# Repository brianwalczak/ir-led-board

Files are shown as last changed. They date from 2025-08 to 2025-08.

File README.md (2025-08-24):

# `ir-led-board`
A custom circuit connecting 16 high-current IR LEDs, designed for integration with Raspberry Pi and imaging projects.

Check out my [JOURNAL.md](JOURNAL.md) for updates and progress!

> [!NOTE]  
> All custom footprints in this project, as well as 3D print files, were created by me and are freely available under the MIT license. You are completely welcome to use, modify, and distribute them without any restrictions.

#### PCB Design
A custom-designed printed circuit board, designed in KiCad 9.0, allowing you to control 16 IR LEDs in groups of four. This PCB was designed as an easy way to connect the components and use them via GPIO pins on the Raspberry Pi.

PCB Design

👉 [Read More](KiCad_PCB/README.md)

#### 3D Model (case)
A 3D printable case, designed in Fusion 360, made to securely hold the board and its components, as well as providing protection to prevent damage to the board.

3D Design
<br>
STL Model

👉 [Read More](3D_Print/README.md)

#### Bill of Materials (BOM)

| Qty | Part Number | Total Price |
|-----|---|---|
| 5 | JLCPCB: PCB Print | $5.30 |
| 1 | Raspberry Pi Camera 3 NoIR | $25.00 |
| 1 | Raspberry Pi 5 Camera Cable | $1.10 |
| 16  | SFH 4556-AW (850nm IR LEDs) | $9.47 |
| 16  | CFM12JT43R0 (43 Ohms resistor) | $0.58 |
| 4 | IRLB8743PBF (MOSFETs) | $4.76 |
| 4 | DC0011 (thermal pads) | $2.20 |
| 4 | CF14JT100R (100 Ohms resistor) | $0.24 |
| 4 | CF14JT100K (100K Ohms resistor) | $0.24 |
| 1 | PPPC061LGBN-RC (90-degree connector) | $0.57 |
| | **Total** | **$49.46**  |

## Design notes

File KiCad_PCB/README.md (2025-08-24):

# `ir-led-board` - KiCad PCB
> [!NOTE]  
> All custom footprints in this project were created by me and are freely available under the MIT license. You are completely welcome to use, modify, and distribute them without any restrictions.

Welcome! This folder includes a custom-designed printed circuit board for the `ir-led-board`, allowing you to control 16 IR LEDs in groups of four. This PCB was designed as an easy way to connect the components and use them via GPIO pins on the Raspberry Pi.

This PCB was designed in KiCad (you can import it with `File > Open Project` and exported as a ready-to-print Gerber file. This PCB can be printed for about **~$2.00** (quantity of 5) on [JLCPCB](https://jlcpcb.com/) (not sponsored).

**All routing has been automatically done by [Freerouting](https://github.com/freerouting/freerouting): an open-source auto-router for KiCad, built with Java.**

#### Schematic
Schematic

#### PCB Design
PCB Design

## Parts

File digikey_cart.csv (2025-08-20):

Index | Quantity | Part Number | Manufacturer Part Number | Description | Customer Reference | Available | Backorder | Unit Price | Extended Price USD
1 | 16 | S43HCT-ND | CFM12JT43R0 | RES 43 OHM 5% 1/2W AXIAL | 16x needed, for each IR LED | 16 | 0 | 0.03100 | 0.50
2 | 16 | 475-SFH4556-AW-ND | SFH 4556-AW | RADIAL T1 3/4 | 16x needed, 4 per group | 16 | 0 | 0.59200 | 9.47
3 | 1 | 2648-SC0873-ND | SC0873 | RASPBERRY PI CAMERA 3 NOIR | Camera used for Near-IR imaging | 1 | 0 | 25.00000 | 25.00
4 | 4 | IRLB8743PBF-ND | IRLB8743PBF | MOSFET N-CH 30V 78A TO220AB | Used to control 4 groups of LEDs | 4 | 0 | 1.19000 | 4.76
5 | 10 | CF14JT100RCT-ND | CF14JT100R | RES 100 OHM 5% 1/4W AXIAL | [10x is cheaper] Used at the gate to GPIO pin | 10 | 0 | 0.02100 | 0.21
6 | 10 | CF14JT100KCT-ND | CF14JT100K | RES 100K OHM 5% 1/4W AXIAL | [10x is cheaper] Pull-down resistor (Gate toGND) | 10 | 0 | 0.02100 | 0.21
7 | 1 | S5481-ND | PPPC061LGBN-RC | CONN HDR 6POS 0.1 GOLD PCB R/A | 90 degree connector for jumper wires | 1 | 0 | 0.57000 | 0.57
8 | 4 | 1168-1804-ND | DC0011/08-TI900-0.12-2A | THERM PAD 19.05MMX12.7MM W/ADH | Thermal pad for MOSFETs | 4 | 0 | 0.55000 | 2.20
9 | 1 | 2648-SC1129-ND | SC1129 | RPI 5 CAMERA CABLE 300MM | The 200mm is out of stock... | 1 | 0 | 2.00000 | 2.00

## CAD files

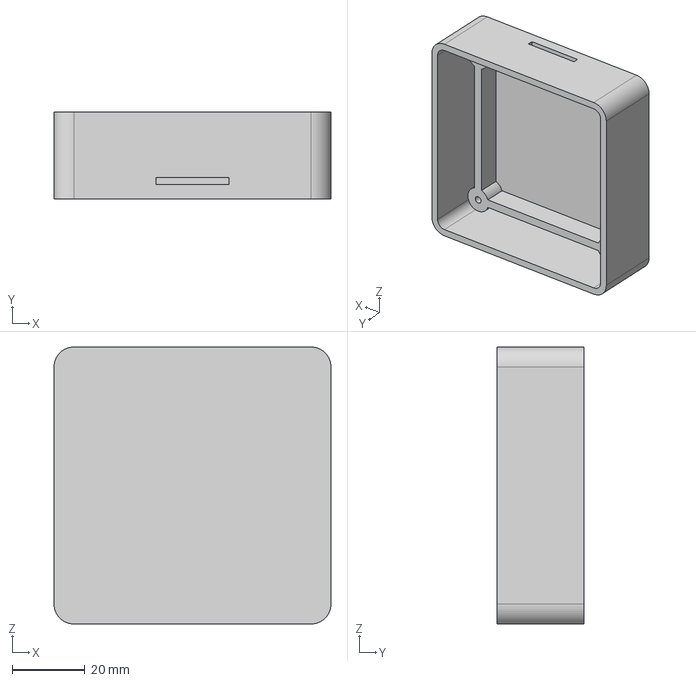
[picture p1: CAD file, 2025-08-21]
3D_Print/ir-led-board v5.step
76.4 x 24.0 x 76.4 mm

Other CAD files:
3D_Print/ir-led-board v5.stl

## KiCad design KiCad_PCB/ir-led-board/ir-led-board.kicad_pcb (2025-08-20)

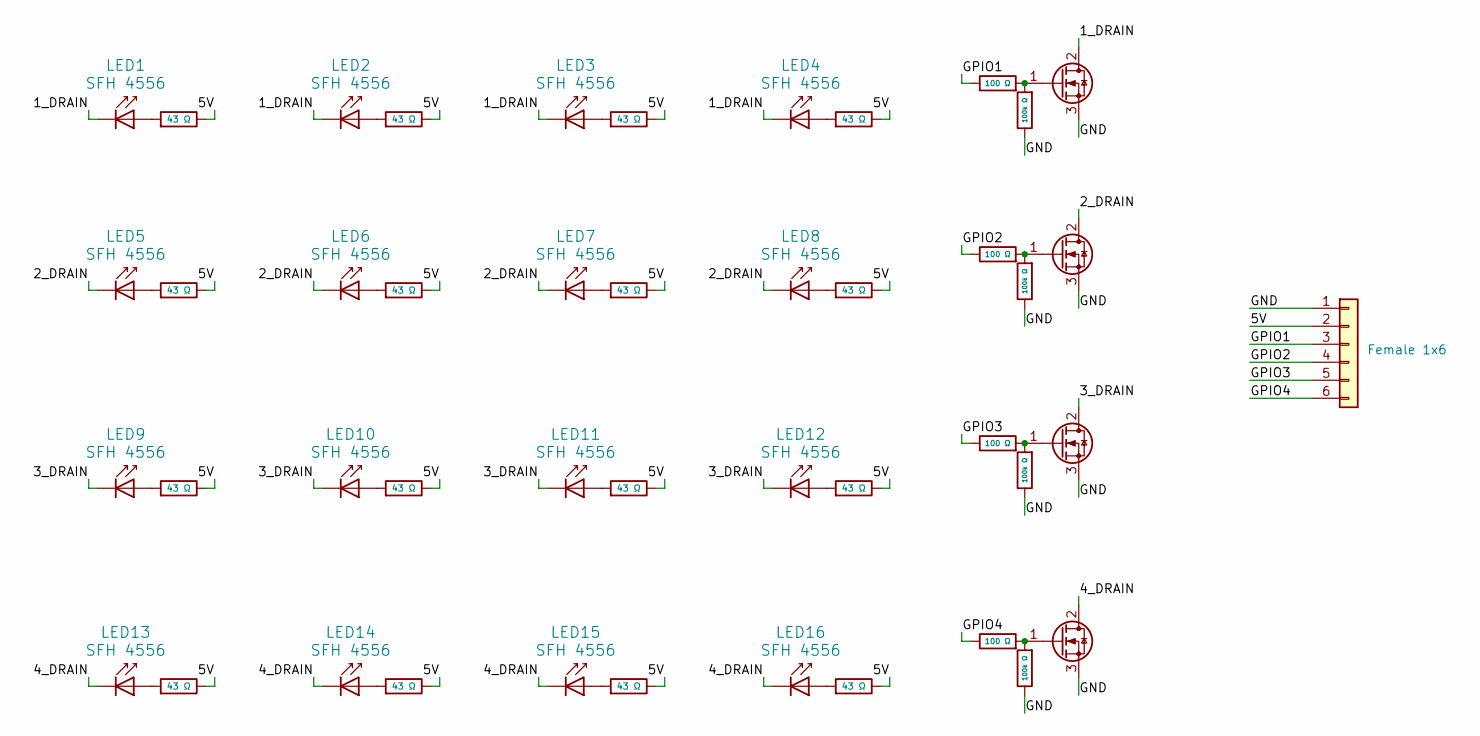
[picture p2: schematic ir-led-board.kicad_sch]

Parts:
F1: Female 1x6; PinHeader_1x06_P2.54mm_Horizontal
Group_1, Group_2, Group_3, Group_4: Q_NMOS_GDS; IRLB8743PBF
LED1, LED2, LED3, LED4, LED5, LED6, LED7, LED8, LED9, LED10, LED11, LED12, LED13, LED14, LED15, LED16: SFH 4556; SFH_4556
R1, R2, R3, R4, R5, R6, R7, R8, R9, R10, R11, R12, R13, R14, R15, R16: 43 Ω; CFM12JT43R0
R_100K_1, R_100K_2, R_100K_3, R_100K_4: 100k Ω; CF14JT100K
R_100_1, R_100_2, R_100_3, R_100_4: 100 Ω; CF14JT100R

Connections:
/1_DRAIN: Group_1.2 (D), LED1.1 (K), LED2.1 (K), LED3.1 (K), LED4.1 (K)
/2_DRAIN: Group_2.2 (D), LED5.1 (K), LED6.1 (K), LED7.1 (K), LED8.1 (K)
/3_DRAIN: Group_3.2 (D), LED9.1 (K), LED10.1 (K), LED11.1 (K), LED12.1 (K)
/4_DRAIN: Group_4.2 (D), LED13.1 (K), LED14.1 (K), LED15.1 (K), LED16.1 (K)
/5V: F1.2, R1.1, R2.1, R3.1, R4.1, R5.1, R6.1, R7.1, R8.1, R9.1, R10.1, R11.1, R12.1, R13.1, R14.1, R15.1, R16.1
/GND: F1.1, Group_1.3 (S), Group_2.3 (S), Group_3.3 (S), Group_4.3 (S), R_100K_1.1, R_100K_2.1, R_100K_3.1, R_100K_4.1
/GPIO1: F1.3, R_100_1.1
/GPIO2: F1.4, R_100_2.1
/GPIO3: F1.5, R_100_3.1
/GPIO4: F1.6, R_100_4.1
unnamed: Group_1.1 (G), R_100K_1.2, R_100_1.2
unnamed: Group_2.1 (G), R_100K_2.2, R_100_2.2
unnamed: Group_3.1 (G), R_100K_3.2, R_100_3.2
unnamed: Group_4.1 (G), R_100K_4.2, R_100_4.2
unnamed: LED1.2 (A), R1.2
unnamed: LED2.2 (A), R2.2
unnamed: LED3.2 (A), R3.2
unnamed: LED4.2 (A), R4.2
unnamed: LED5.2 (A), R5.2
unnamed: LED6.2 (A), R6.2
unnamed: LED7.2 (A), R7.2
unnamed: LED8.2 (A), R8.2
unnamed: LED9.2 (A), R9.2
unnamed: LED10.2 (A), R10.2
unnamed: LED11.2 (A), R11.2
unnamed: LED12.2 (A), R12.2
unnamed: LED13.2 (A), R13.2
unnamed: LED14.2 (A), R14.2
unnamed: LED15.2 (A), R15.2
unnamed: LED16.2 (A), R16.2

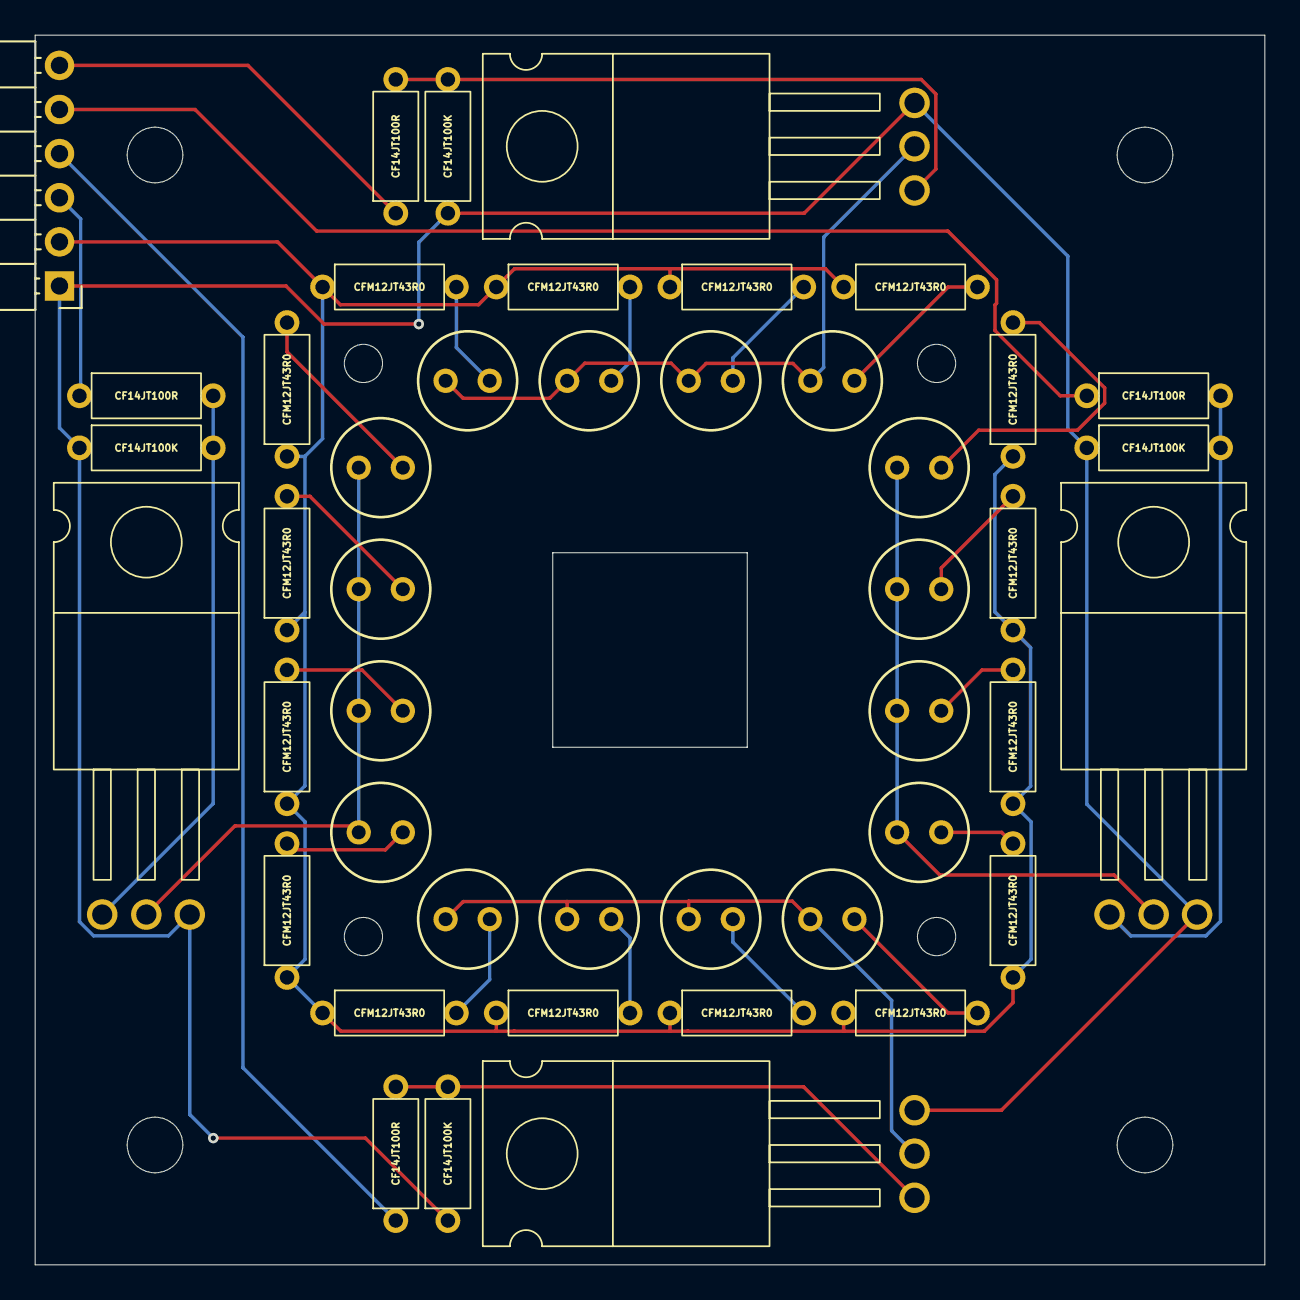
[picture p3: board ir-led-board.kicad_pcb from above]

Board: 2 copper layers, 70.8 x 70.8 mm, 53 parts (0 on the bottom side), 30 nets.

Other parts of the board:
MOUNT_1, MOUNT_2, MOUNT_3, MOUNT_4: MountingHole_2.2mm_M2
OUTER_MOUNT_1, OUTER_MOUNT_2, OUTER_MOUNT_3, OUTER_MOUNT_4: MountingHole_3.2mm_M3

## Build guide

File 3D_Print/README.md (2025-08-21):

# `ir-led-board` - 3D Print
> [!NOTE]  
> All 3D print files in this project were created by me and are freely available under the MIT license. You are completely welcome to use, modify, and distribute them without any restrictions.

Welcome! This folder includes a custom-designed 3D printable case for the `ir-led-board`. The model was designed to securely hold the board and its components, as well as providing protection to prevent damage to the board.

This case was designed in Fusion 360 and features a secure, compact design to attach the PCB with 4x M3 screws. These screws can be threaded straight through the pre-designated mounting holes.

The M3 screws should be round head and 8mm in length. An example set of screws can be found on AliExpress [here](https://www.aliexpress.us/item/3256806672911442.html).

#### 3D Design
3D Design
<br>
STL Model

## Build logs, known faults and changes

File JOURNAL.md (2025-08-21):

---
Title: "IR LED Board"
Author: "Brian Walczak"
Description: "A custom circuit to control an array of 16 high-current IR LEDs. This PCB is designed for integration with a Raspberry Pi and is used for Near-IR imaging projects!"
Created On: "8/9/2025"
---

# August 20th: Designing a protective case.

Final step of the process! Today I designed a simple 3D printable housing to keep the PCB and its components nice and safe. I tried to make the model as compact as possible to save space.

I created the case in Fusion 360 and added some pre-designated mounting holes where I can attach the PCB. It was specifically made to use four M3 screws, 8mm in length!

 

**Total time spent: 1h**

# August 19th: Send to JLCPCB, ordering parts.

Hello! Today I finalized the design and exported the Gerber files to have them manufactured with JLCPCB. I was having trouble with the traces, so I used [Freerouting](https://github.com/freerouting/freerouting): an open-source auto-router for KiCad! This made the process much easier for me (and less stressful).

JLCPCB is estimating a total of $2.00 + $3.30 shipping, pretty solid for a quantity of 5 (in-case I mess up while soldering... heck I probably will).

 

**Total time spent: 15m**

# August 18th: Minor changes on the PCB, almost ready.

Hey, it's been a while! I got busy from school the past few days, but I'm happy to say that I'm done with the PCB design!

I made a few extra modifications, and shifted the position of the IR LEDs so that I can include ~2mm screw holes on each corner. I decided to add these just in case I design a 3D-printed part in the future.

Overall, I'm pretty excited to see how the final board turns out. Next, I'll have to add the traces on the PCB and export the gerber!

Oh, and here's what it looks like:



**Total time spent: 10m**

# August 14th: Finalizing the PCB design

Hi! Today, I've been working on the final step of the building process: designing the PCB. This time was pretty time consuming since KiCad positioning tools kind of suck, so I had to make sure each part was spaced evenly with the help of the Align/Distribute and Positioning Tools.

My goal is to make this PCB as compact as possible, which I was able to perfect after making some small modifications, then printing out a 1:1 sheet of the PCB. The print tool really helped me get an idea of what the final product will look like.

I'm thinking of adding some screw holes around the PCB in the event that I want to attach dividers between each LED group. These would be handy if I'm planning to use IR diffusers or polarizers in the future. As I probably mentioned earlier, the goal with this PCB is to explore how near-IR light interacts with surfaces and veins, and to learn a little more about optics and imaging. Oh, and so I can improve my soldering skills...



**Total time spent: 2h**

# August 13th: Working on the schematic / symbols

I've been working on analyzing the datasheets of my selected components and creating symbols/footprints for them, since I wasn't able to find reliable ones online. The process of creating these took a good chunk of my time, since I wanted to make sure the measurements had millimeter accuracy according to the datasheets. I'd like to make this board as compact as possible, while still making it easy to solder on.

Also, I haven't used KiCad in a while, so I spent quite a lot of time getting used to it again. I've designed a simple schematic for the project using some net labels and I'm currently working on PCB design next!



**Total time spent: 2.5h**

# August 12th: Almost done choosing parts!

Good afternoon! Unfortunately, school has started for me today, so I didn't get much done. It might sound crazy, but I spent roughly 2 hours yesterday searching for parts. It turns out that finding affordable parts that **will actually work for your project** isn't easy. I've basically seen the entire DigiKey catalog for MOSFETs at this point lol.

I will say that Perplexity has been a lifesaver for most of this research. Being someone who's never worked with MOSFETs before, I just found out that there actually isn't an ideal MOSFET for 3.3V signals that's both affordable and available (most are obsolete on DigiKey). After looking for quite a while, I've basically concluded that the **IRLB8743PBF** N-Channel MOSFET will be the closest to what I'd need for this kind of project.

Even though it's not rated for 3.3V by the manufacturer, it's been used in many different projects and seems to be the most recommended by the community, even though it works better with 5V. It's definitely not a 100% ideal solution for most applications, but I think in this case it'll work just fine.

I'll also be getting some `100 Ω` resistors to prevent a big surge of current at the gate, and `100k Ω` pull-down resistors from the gate to GND so it doesn't randomly turn on when the Raspberry Pi is off.

The total comes out to about $45 before shipping, not bad! It's time to get to work in KiCad!

 


**Total time spent: 1h**

# August 11th: This may be more challenging than I assumed.

Hello again! I've been looking into a bunch of different ways to wire up all these IR LEDs efficiently. I've concluded that DigiKey will be the best place to get these parts, since they have a lot available in-stock and shipping times are usually the fastest.

My first problem is that I realized is it might be tricky to source the current for each LED. For this project, I'd like to be able to control these LEDs in groups of 4, essentially allowing me to turn groups on and off via the GPIO pins on the Raspberry Pi.

After doing some research, it looks like I may need to use MOSFETs to group these and ensure they can be switched reliably. There are some other alternative options (such as BJT's), but MOSFETs will be the best choice for my use case. That being said, I'll need to connect the PCB to the 5V pin on the Raspberry Pi to source enough power.

I've also decided that I'll be using `43 Ω` resistors for the LEDs, which will limit them to ~80mA of current. I've been eyeing [these](https://www.digikey.com/en/products/detail/ams-osram-usa-inc/SFH-4556-AW/7325582) IR LEDs on DigiKey for this project, since they offer 100mA in forward current and a 1.5V forward voltage.

```
Total Voltage = (5V - 1.5V) = 3.5V

Voltage / Current = Resistance
3.5V / 0.08A = 43.75 ohms
```
##### (here's how I got that number by the way)

I have already selected the camera I'll be using, and that's the **Raspberry Pi Camera 3 Module (NoIR Edition)**. I'm currently researching the other components needed to get this project done (including MOSFETs, other resistors, etc).



**Total time spent: 2h**

# August 10th: Time to research!

Welcome! This is a hardware project I'm looking to work on for the next few weeks. My goal is to design and build a PCB in KiCad that can simplify the control of 16 high-current (probably around ~50-100mA) IR LEDs for an imaging project.

For this project, I've decided to use my existing Raspberry Pi 5 to cut costs. It's already a perfect choice for this project, and I've been trying to figure out what I can do with it, so that's what we're doing here.

I've only ever created a PCB once (in KiCad as well). It was for a Flipper-Zero-style SubGHz device that captured, replayed, and analyzed SubGHz frequencies. It's called BKFZ SubGHz, you can check it out [here](https://github.com/brianwalczak/BKFZ-SubGHz). That being said, this was quite a simple PCB, and honestly wasn't entirely necessary for the project.

Before I get started with creating this PCB in KiCad, I'll need to spend the next few days researching my options and finding the parts I need to make this project. Ideally it should use 16 IR LEDs to make sure the surface is evenly illuminated. I'd like to be able to control the LEDs in groups of 4.



**Total time spent: 30m**

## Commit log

2025-08-20 Include cart details from DigiKey
    [digikey_cart.csv, digikey_cart.xlsx]
2025-08-20 Include KiCad files + gerber file
    [ir-led-board.kicad_pcb, ir-led-board.kicad_sch]
2025-08-21 Add 3D design
    [ir-led-board v5.step, ir-led-board v5.stl]
2025-08-21 this is what happens when you're tired.. 😴
2025-08-23 Enhance README with PCB and 3D model information
    Added sections for PCB design and 3D model details.
2025-08-24 Add Bill of Materials section to README
    Added a Bill of Materials (BOM) section with details on components and pricing.
